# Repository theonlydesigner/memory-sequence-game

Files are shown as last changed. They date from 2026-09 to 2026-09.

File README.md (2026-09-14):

# Memory Sequence Game

A custom Simon Says-style memory game hardware project featuring an onboard Arduino Nano, multi-colored LED array, tactile pushbuttons and dual haptic/buzzer feedback [because pressing buttons without audio-visual chaos is boring].

3D View Preview

## Overview

This project is an all-in-one memory game board built around the Arduino Nano. It combines 4 distinct color LEDs (Red, Green, Blue, Yellow), 4 matching tactile buttons, audio tone generation and vibration feedback into a clean, standalone PCB footprint. Designed for simple assembly, standalone power handling and easy reprogramming.

## Features

* **Dynamic Sequence Generation:** Randomized color patterns generated each level with an integrated countdown timer to force quick decisions.
* **Audio-Haptic Feedback:** Each button press triggers a dedicated pitch note alongside vibration motor/buzzer feedback.
* **Dedicated Power Delivery:** Onboard DC barrel jack and voltage regulator setup to run off external DC power without frying components.
* **Hardware Controls:** Dual slide switches dedicated to master power toggle and volume/feedback control.
* **Repurposable Microcontroller Hub:** Built around female pin headers for the Arduino Nano, allowing the core board to be reused for other dev projects.

## Gallery

### Schematic & Layout

| Schematic Design | PCB 2D Layout Top | PCB 2D Layout Bottom |
| :---: | :---: | :---: |
| Schematic | PCB Top | PCB Bottom |

### 3D Model Renders

| Perspective View | Top Isometric |
| :---: | :---: |
| 3D View 1 | 3D View 2 |

| Side Profile | Rear Power & Port Angle |
| :---: | :---: |
| 3D View 3 | 3D View 4 |

## Bill of Materials (BOM)

| Item | Quantity | Description / Package |
| :--- | :---: | :--- |
| **Arduino Nano** | 1 | Microcontroller (with female pin headers) |
| **Colored LEDs** | 4 | 1x Red, 1x Green, 1x Blue, 1x Yellow |
| **Current Limiting Resistors** | 4 | 220Ω through-hole / axial |
| **Tactile Pushbuttons** | 4 | Standard 4-pin momentary switches |
| **Feedback Motor / Buzzer** | 1 | Vibration motor or piezo buzzer |
| **DC Barrel Jack** | 1 | Standard DC power input jack |
| **Slide Switches** | 2 | SPDT switches (Power & Volume controls) |
| **Voltage Regulator** | 1 | Onboard linear voltage regulator |
| **JST Connector** | 1 | Auxiliary power connector |

## How to Assemble

1. **Low-Profile Components:** Solder the 4x 220Ω current-limiting resistors first.
2. **Semiconductors & Switches:** Mount the 4 LEDs (pay attention to anode/cathode orientation), voltage regulator and slide switches.
3. **Interactive Hardware:** Solder the 4 tactile pushbuttons, DC barrel jack, vibration motor/buzzer and JST connector.
4. **Header Sockets:** Solder the female pin headers for the Arduino Nano socket.
5. **Mount & Flash:** Insert the Arduino Nano into the headers, upload the game code via USB-C/Mini-USB and flip the power switch.

## Credits

* **Designer:** Pratham Rupera (`theonlydesigner`)
* **Platform:** Built for Hack Club

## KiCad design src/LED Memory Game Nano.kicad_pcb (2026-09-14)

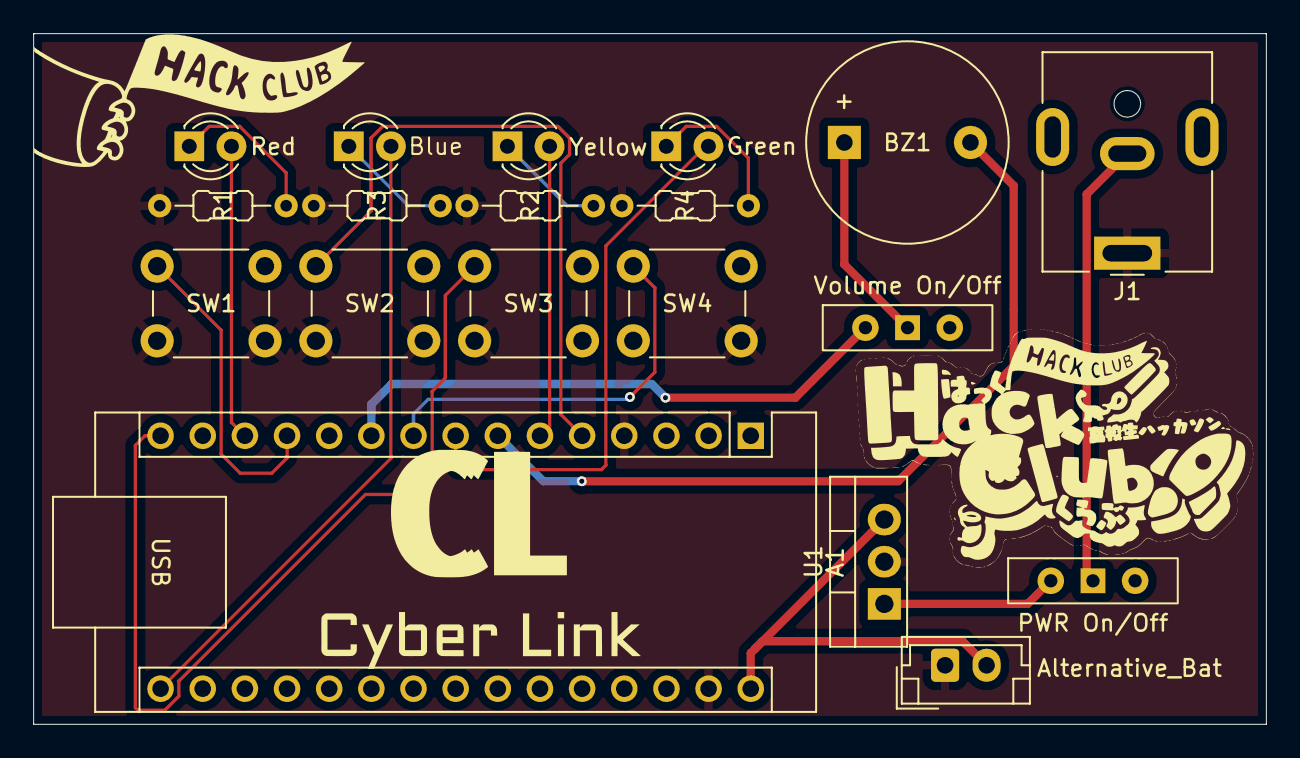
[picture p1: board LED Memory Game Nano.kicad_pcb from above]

Board: 2 copper layers, 74.3 x 41.6 mm, 19 parts (0 on the bottom side), 19 nets.

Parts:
A1: Arduino_Nano_v3.x; Arduino_Nano
Alternative_Bat: JST_EH_B2B-EH-A_1x02_P2.50mm_Vertical
BZ1: Buzzer; Buzzer_12x9.5RM7.6
D1: Red; LED_D3.0mm
D2: Yellow; LED_D3.0mm
D3: Blue; LED_D3.0mm
D4: Green; LED_D3.0mm
J1: DC Barrel; BarrelJack_CUI_PJ-063AH_Horizontal
PWR On/Off: SW_Wuerth_450301014042; SW_Slide-03_Wuerth-WS-SLTV_10x2.5x6.4_P2.54mm
R1, R2, R3, R4: 220ohm; R_Axial_DIN0204_L3.6mm_D1.6mm_P7.62mm_Horizontal
SW1: R; SW_PUSH_6mm_RW
SW2: G; SW_PUSH_6mm_RW
SW3: B; SW_PUSH_6mm_RW
SW4: Y; SW_PUSH_6mm_RW
U1: LM340AT-5.0; TO-220-3_Vertical
Volume On/Off: SW_Wuerth_450301014042; SW_Slide-03_Wuerth-WS-SLTV_10x2.5x6.4_P2.54mm

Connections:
+5V: A1.27 (+5V), A1.30 (VIN), Alternative_Bat.2, U1.3 (OUT)
B+: A1.10 (D7), Volume On/Off.2 (C)
B-: A1.7 (D4), BZ1.2 (-)
BTN_B: A1.15 (D12), SW3.1 (A), SW3.2 (A)
BTN_G: A1.5 (D2), SW2.1 (A), SW2.2 (A)
BTN_R: A1.12 (D9), SW1.1 (A), SW1.2 (A)
BTN_Y: A1.9 (D6), SW4.1 (A), SW4.2 (A)
DC: PWR On/Off.2 (C), U1.1 (IN)
GND: A1.4 (GND), A1.29 (GND), Alternative_Bat.1, J1.1, R1.2, R2.2, R3.2, R4.2, SW1.3 (B), SW1.4 (B), SW2.3 (B), SW2.4 (B), SW3.3 (B), SW3.4 (B), SW4.3 (B), SW4.4 (B), U1.2
LED_B: A1.16 (D13), D3.2 (A)
LED_G: A1.6 (D3), D2.2 (A)
LED_R: A1.13 (D10), D1.2 (A)
LED_Y: A1.8 (D5), D4.2 (A)
unnamed: BZ1.1 (+), Volume On/Off.1 (B)
unnamed: D1.1 (K), R1.1
unnamed: D2.1 (K), R2.1
unnamed: D3.1 (K), R3.1
unnamed: D4.1 (K), R4.1
unnamed: J1.2, PWR On/Off.1 (B)

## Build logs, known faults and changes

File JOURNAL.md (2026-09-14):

---
title: "memory sequence game"
author: "theonlydesigner"
description: "a led memory game with an arduino nano, dc barrel jack, jst connector, buzzer/vibration motor and more!"
created_at: "2026-09-15"
---

# september 15(log 1): the crazy marathon session & schematic start
pulled off an absolutely insane one-day work session today to get this entire board designed from scratch. started out by dropping in the core symbols to the schematic: leds, tactile buttons, current limiting resistors, the arduino nano and a buzzer. created the net labels and started the initial wiring spaghetti. spent some time brainstorming the rest of the features and mapping out a solid plan [before i lose my mind later].

https://github.com/user-attachments/assets/3a849660-60fd-400a-b150-f533264552a7

**total time spent: 31 minutes**

# september 15(log 2): finalizing schematic & layout theory
after the initial brainstorming and a long break [because staring at raw schematics drains my soul], i added all the final peripheral components and wired them into the main matrix. spent some time visualizing the physical pcb layout so i don't paint myself into a corner later when it comes to trace routing.

https://github.com/user-attachments/assets/6e46e15e-fe6b-4ae6-a1a1-a7f3514cc424

**total time spent: 1 hour 17 minutes**

# september 15(log 3): pcb layout speedrun
locked in the finalized schematic and aggressively transitioned to the pcb editor. assigned footprints to every single component and started placing them according to my mental layout plan. it's basically just playing digital tetris but if you mess up the board doesn't actually work.

https://github.com/user-attachments/assets/c51fe556-855b-412e-b04d-bd3921c337f6

**total time spent: 1 hour 4 minutes**

# september 15(log 4): routing hell & final touches
finally finished the whole pcb routing and getting all the copper traces down. threw in some hack club silkscreen art because empty pcbs look boring. added a jst connector for a battery and threw in a dc barrel jack too [idk who would connect a desktop wall supply to a portable memory game lol, but i added an ldo voltage regulator just in case someone tries to fry it]. the board is finally done.

https://github.com/user-attachments/assets/89f49a14-93c5-45c5-82a5-db46f538ad68

**total time spent: 1 hour 19 minutes**

---
**total time worked to finish project designing: 4 hours 11 minutes** [fixed the final calculation because math is hard after a marathon session]

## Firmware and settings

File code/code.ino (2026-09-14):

#define NOTE_B0 31
#define NOTE_C1 33
#define NOTE_CS1 35
#define NOTE_D1 37
#define NOTE_DS1 39
#define NOTE_E1 41
#define NOTE_F1 44
#define NOTE_FS1 46
#define NOTE_G1 49
#define NOTE_GS1 52
#define NOTE_A1 55
#define NOTE_AS1 58
#define NOTE_B1 62
#define NOTE_C2 65
#define NOTE_CS2 69
#define NOTE_D2 73
#define NOTE_DS2 78
#define NOTE_E2 82
#define NOTE_F2 87
#define NOTE_FS2 93
#define NOTE_G2 98
#define NOTE_GS2 104
#define NOTE_A2 110
#define NOTE_AS2 117
#define NOTE_B2 123
#define NOTE_C3 131
#define NOTE_CS3 139
#define NOTE_D3 147
#define NOTE_DS3 156
#define NOTE_E3 165
#define NOTE_F3 175
#define NOTE_FS3 185
#define NOTE_G3 196
#define NOTE_GS3 208
#define NOTE_A3 220
#define NOTE_AS3 233
#define NOTE_B3 247
#define NOTE_C4 262
#define NOTE_CS4 277
#define NOTE_D4 294
#define NOTE_DS4 311
#define NOTE_E4 330
#define NOTE_F4 349
#define NOTE_FS4 370
#define NOTE_G4 392
#define NOTE_GS4 415
#define NOTE_A4 440
#define NOTE_AS4 466
#define NOTE_B4 494
#define NOTE_C5 523
#define NOTE_CS5 554
#define NOTE_D5 587
#define NOTE_DS5 622
#define NOTE_E5 659
#define NOTE_F5 698
#define NOTE_FS5 740
#define NOTE_G5 784
#define NOTE_GS5 831
#define NOTE_A5 880
#define NOTE_AS5 932
#define NOTE_B5 988
#define NOTE_C6 1047
#define NOTE_CS6 1109
#define NOTE_D6 1175
#define NOTE_DS6 1245
#define NOTE_E6 1319
#define NOTE_F6 1397
#define NOTE_FS6 1480
#define NOTE_G6 1568
#define NOTE_GS6 1661
#define NOTE_A6 1760
#define NOTE_AS6 1865
#define NOTE_B6 1976
#define NOTE_C7 2093
#define NOTE_CS7 2217
#define NOTE_D7 2349
#define NOTE_DS7 2489
#define NOTE_E7 2637
#define NOTE_F7 2794
#define NOTE_FS7 2960
#define NOTE_G7 3136
#define NOTE_GS7 3322
#define NOTE_A7 3520
#define NOTE_AS7 3729
#define NOTE_B7 3951
#define NOTE_C8 4186
#define NOTE_CS8 4435
#define NOTE_D8 4699
#define NOTE_DS8 4978

#define CHOICE_OFF 0
#define CHOICE_NONE 0
#define CHOICE_RED (1 << 0)
#define CHOICE_GREEN (1 << 1)
#define CHOICE_BLUE (1 << 2)
#define CHOICE_YELLOW (1 << 3)
#define LED_RED 10
#define LED_GREEN 3
#define LED_BLUE 13
#define LED_YELLOW 5
#define BUTTON_RED 9
#define BUTTON_GREEN 2
#define BUTTON_BLUE 12
#define BUTTON_YELLOW 6
#define BUZZER1 4
#define BUZZER2 7
#define ROUNDS_TO_WIN 13
#define ENTRY_TIME_LIMIT 3000
#define MODE_MEMORY 0
#define MODE_BATTLE 1
#define MODE_BEEGEES 2

byte gameMode = MODE_MEMORY;
byte gameBoard[32];
byte gameRound = 0;

void setup() {
  pinMode(BUTTON_RED, INPUT_PULLUP);
  pinMode(BUTTON_GREEN, INPUT_PULLUP);
  pinMode(BUTTON_BLUE, INPUT_PULLUP);
  pinMode(BUTTON_YELLOW, INPUT_PULLUP);
  pinMode(LED_RED, OUTPUT);
  pinMode(LED_GREEN, OUTPUT);
  pinMode(LED_BLUE, OUTPUT);
  pinMode(LED_YELLOW, OUTPUT);
  pinMode(BUZZER1, OUTPUT);
  pinMode(BUZZER2, OUTPUT);
  gameMode = MODE_MEMORY;
  if (checkButton() == CHOICE_YELLOW) play_beegees();
  if (checkButton() == CHOICE_GREEN) {
    gameMode = MODE_BATTLE;
    setLEDs(CHOICE_GREEN);
    toner(CHOICE_GREEN, 150);
    setLEDs(CHOICE_RED | CHOICE_BLUE | CHOICE_YELLOW);
    while(checkButton() != CHOICE_NONE);
  }
  play_winner();
}

void loop() {
  attractMode();
  setLEDs(CHOICE_RED | CHOICE_GREEN | CHOICE_BLUE | CHOICE_YELLOW);
  delay(1000);
  setLEDs(CHOICE_OFF);
  delay(250);
  if (gameMode == MODE_MEMORY) {
    if (play_memory() == true) play_winner();
    else play_loser();
  }
  if (gameMode == MODE_BATTLE) {
    play_battle();
    play_loser();
  }
}

boolean play_memory(void) {
  randomSeed(millis());
  gameRound = 0;
  while (gameRound < ROUNDS_TO_WIN) {
    add_to_moves();
    playMoves();
    for (byte currentMove = 0 ; currentMove < gameRound ; currentMove++) {
      byte choice = wait_for_button();
      if (choice == 0) return false;
      if (choice != gameBoard[currentMove]) return false;
    }
    delay(1000);
  }
  return true;
}

boolean play_battle(void) {
  gameRound = 0;
  while (1) {
    byte newButton = wait_for_button();
    gameBoard[gameRound++] = newButton;
    for (byte currentMove = 0 ; currentMove < gameRound ; currentMove++) {
      byte choice = wait_for_button();
      if (choice == 0) return false;
      if (choice != gameBoard[currentMove]) return false;
    }
    delay(100);
  }
  return true;
}

void playMoves(void) {
  for (byte currentMove = 0 ; currentMove < gameRound ; currentMove++) {
    toner(gameBoard[currentMove], 150);
    delay(150);
  }
}

void add_to_moves(void) {
  byte newButton = random(0, 4);
  if(newButton == 0) newButton = CHOICE_RED;
  else if(newButton == 1) newButton = CHOICE_GREEN;
  else if(newButton == 2) newButton = CHOICE_BLUE;
  else if(newButton == 3) newButton = CHOICE_YELLOW;
  gameBoard[gameRound++] = newButton;
}

void setLEDs(byte leds) {
  digitalWrite(LED_RED, (leds & CHOICE_RED) ? HIGH : LOW);
  digitalWrite(LED_GREEN, (leds & CHOICE_GREEN) ? HIGH : LOW);
  digitalWrite(LED_BLUE, (leds & CHOICE_BLUE) ? HIGH : LOW);
  digitalWrite(LED_YELLOW, (leds & CHOICE_YELLOW) ? HIGH : LOW);
}

byte wait_for_button(void) {
  long startTime = millis();
  while ((millis() - startTime) < ENTRY_TIME_LIMIT) {
    byte button = checkButton();
    if (button != CHOICE_NONE) {
      toner(button, 150);
      while(checkButton() != CHOICE_NONE);
      delay(10);
      return button;
    }
  }
  return CHOICE_NONE;
}

byte checkButton(void) {
  if (digitalRead(BUTTON_RED) == 0) return(CHOICE_RED);
  else if (digitalRead(BUTTON_GREEN) == 0) return(CHOICE_GREEN);
  else if (digitalRead(BUTTON_BLUE) == 0) return(CHOICE_BLUE);
  else if (digitalRead(BUTTON_YELLOW) == 0) return(CHOICE_YELLOW);
  return(CHOICE_NONE);
}

void toner(byte which, int buzz_length_ms) {
  setLEDs(which);
  switch(which) {
    case CHOICE_RED:
      buzz_sound(buzz_length_ms, 1136);
      break;
    case CHOICE_GREEN:
      buzz_sound(buzz_length_ms, 568);
      break;
    case CHOICE_BLUE:
      buzz_sound(buzz_length_ms, 851);
      break;
    case CHOICE_YELLOW:
      buzz_sound(buzz_length_ms, 638);
      break;
  }
  setLEDs(CHOICE_OFF);
}

void buzz_sound(int buzz_length_ms, int buzz_delay_us) {
  long buzz_length_us = buzz_length_ms * (long)1000;
  while (buzz_length_us > (buzz_delay_us * 2)) {
    buzz_length_us -= buzz_delay_us * 2;
    digitalWrite(BUZZER1, LOW);
    digitalWrite(BUZZER2, HIGH);
    delayMicroseconds(buzz_delay_us);
    digitalWrite(BUZZER1, LOW);
    digitalWrite(BUZZER2, LOW);
    delayMicroseconds(buzz_delay_us);
  }
  digitalWrite(BUZZER1, LOW);
  digitalWrite(BUZZER2, LOW);
}

void play_winner(void) {
  setLEDs(CHOICE_GREEN | CHOICE_BLUE);
  winner_sound();
  setLEDs(CHOICE_RED | CHOICE_YELLOW);
  winner_sound();
  setLEDs(CHOICE_GREEN | CHOICE_BLUE);
  winner_sound();
  setLEDs(CHOICE_RED | CHOICE_YELLOW);
  winner_sound();
}

void winner_sound(void) {
  for (byte x = 250 ; x > 70 ; x--) {
    for (byte y = 0 ; y < 3 ; y++) {
      digitalWrite(BUZZER2, HIGH);
      digitalWrite(BUZZER1, LOW);
      delayMicroseconds(x);
      digitalWrite(BUZZER2, LOW);
      digitalWrite(BUZZER1, LOW);
      delayMicroseconds(x);
    }
  }
  digitalWrite(BUZZER1, LOW);
  digitalWrite(BUZZER2, LOW);
}

void play_loser(void) {
  setLEDs(CHOICE_RED | CHOICE_GREEN);
  buzz_sound(255, 1500);
  setLEDs(CHOICE_BLUE | CHOICE_YELLOW);
  buzz_sound(255, 1500);
  setLEDs(CHOICE_RED | CHOICE_GREEN);
  buzz_sound(255, 1500);
  setLEDs(CHOICE_BLUE | CHOICE_YELLOW);
  buzz_sound(255, 1500);
}

void attractMode(void) {
  while(1) {
    setLEDs(CHOICE_RED);
    delay(100);
    if (checkButton() != CHOICE_NONE) return;
    setLEDs(CHOICE_BLUE);
    delay(100);
    if (checkButton() != CHOICE_NONE) return;
    setLEDs(CHOICE_GREEN);
    delay(100);
    if (checkButton() != CHOICE_NONE) return;
    setLEDs(CHOICE_YELLOW);
    delay(100);
    if (checkButton() != CHOICE_NONE) return;
  }
}

int melody[] = {
  NOTE_G4, NOTE_A4, 0, NOTE_C5, 0, 0, NOTE_G4, 0, 0, 0,
  NOTE_E4, 0, NOTE_D4, NOTE_E4, NOTE_G4, 0,
  NOTE_D4, NOTE_E4, 0, NOTE_G4, 0, 0,
  NOTE_D4, 0, NOTE_E4, 0, NOTE_G4, 0, NOTE_A4, 0, NOTE_C5, 0};

int noteDuration = 115;
int LEDnumber = 0;

void play_beegees() {
  setLEDs(CHOICE_YELLOW);
  toner(CHOICE_YELLOW, 150);
  setLEDs(CHOICE_RED | CHOICE_GREEN | CHOICE_BLUE);
  while(checkButton() != CHOICE_NONE);
  setLEDs(CHOICE_NONE);
  delay(1000);
  digitalWrite(BUZZER1, LOW);
  while(checkButton() == CHOICE_NONE) {
    for (int thisNote = 0; thisNote < 32; thisNote++) {
      changeLED();
      if (melody[thisNote] > 0) {
        int period = 1000000 / melody[thisNote];
        int halfPeriod = period / 2;
        long duration = noteDuration * 1000L;
        while (duration > period) {
          digitalWrite(BUZZER1, LOW);
          digitalWrite(BUZZER2, HIGH);
          delayMicroseconds(halfPeriod);
          digitalWrite(BUZZER1, LOW);
          digitalWrite(BUZZER2, LOW);
          delayMicroseconds(halfPeriod);
          duration -= period;
        }
        digitalWrite(BUZZER1, LOW);
        digitalWrite(BUZZER2, LOW);
      } else {
        digitalWrite(BUZZER1, LOW);
        digitalWrite(BUZZER2, LOW);
        delay(noteDuration);
      }
    }
  }
}

void changeLED(void) {
  setLEDs(1 << LEDnumber);
  LEDnumber++;
  if(LEDnumber > 3) LEDnumber = 0;
}

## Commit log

2026-09-14 Enhance README with project details and instructions
    Added detailed project description, features, gallery, BOM, assembly instructions, and credits to README.
2026-09-14 Add project journal for LED memory game design
    Documented the design process and time spent on a LED memory game project using Arduino Nano.
